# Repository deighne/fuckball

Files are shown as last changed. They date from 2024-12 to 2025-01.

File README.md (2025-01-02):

# FUCKBALL

This trackball is my update and twist on [Brickbots' aball](https://github.com/brickbots/aball) with a lot of inspiration from the [Ploopy Adept](https://github.com/ploopyco/adept-trackball). 

The biggest changes are:

- Built to use PMW3360 / PMW3389 breakout boards
- RP2040-Zero Board to keep things small and modern
- Footprint designed to sit alongside [Sofle v2](https://github.com/josefadamcik/SofleKeyboard) on either side
- A single button, as a treat

## What's the point?

I really like the simplicity of the aball design, but found its quirks kind of irritating to build. Elite-C boards aren't cheap compared to the thousands of nano boards on the market, and handwiring tiny tiny cables leaves a lot of room for error. I felt like there wasn't a great option for a buttonless trackball with a high precision sensor; the Ploopy nano is solidly entry-level, and nicer options like the Ploopy Adept are comparitively big and bulky. I think this strikes a nice balance.

## Why the breakout board and not sensor only? 

At the time of writing (December 2024), the cost difference between just a PMW3389 sensor and the sensor + breakout board with presoldered pins is just a few bucks; it's cheaper to buy the board than to get a custom PCB with assembly like the [Jfedor2 RP2040 + PMW3360 board](https://github.com/jfedor2/rp2040-pmw3360). That should make this more flexible to use other sensors in the future with the same breakout!

## License etc.

GPLv3! Do something weird with this design please.

## Fuckball?

The name wasn't already taken?

## Status

- Gerber files and Kicad are a prototype design; has not yet been printed. No guarantees! (There never are with open source any way)
- Needs BOM, guide, etc. etc. 

## Sources and Inspiration

- [Aball](https://github.com/brickbots/aball)
- [Ploopy Adept](https://github.com/ploopyco/adept-trackball))
- [Sofle](https://github.com/josefadamcik/SofleKeyboard)
- [RP2040+PMW3360](https://github.com/jfedor2/rp2040-pmw3360)

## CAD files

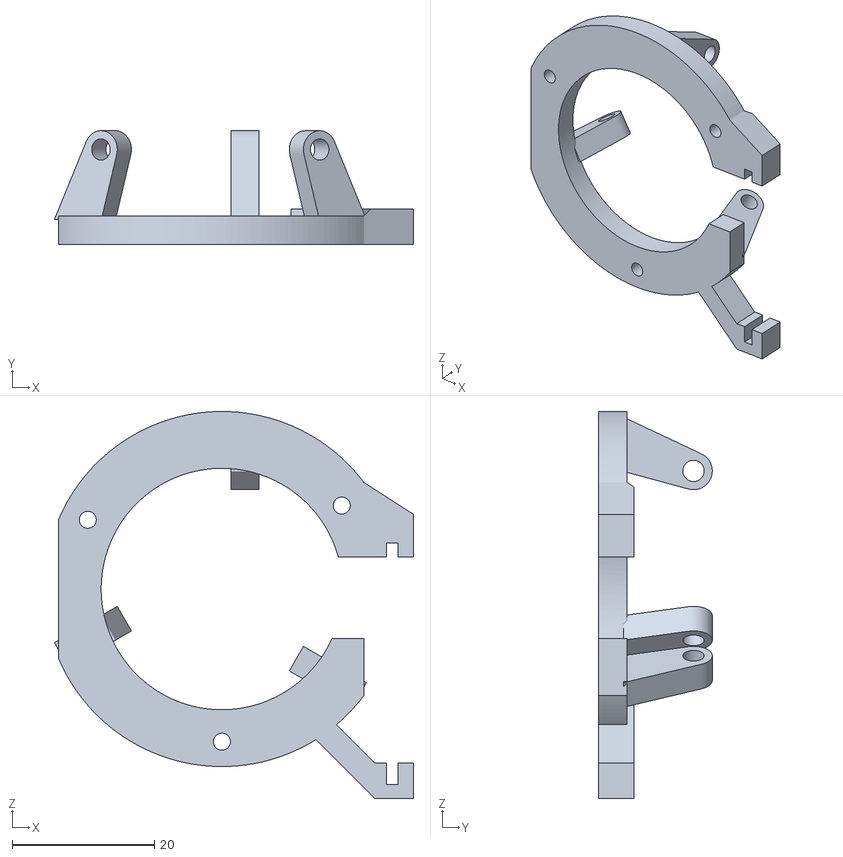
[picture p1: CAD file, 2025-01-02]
3d Printing/vertical_frame_rev4_34mm.stl
50.6 x 16.0 x 54.5

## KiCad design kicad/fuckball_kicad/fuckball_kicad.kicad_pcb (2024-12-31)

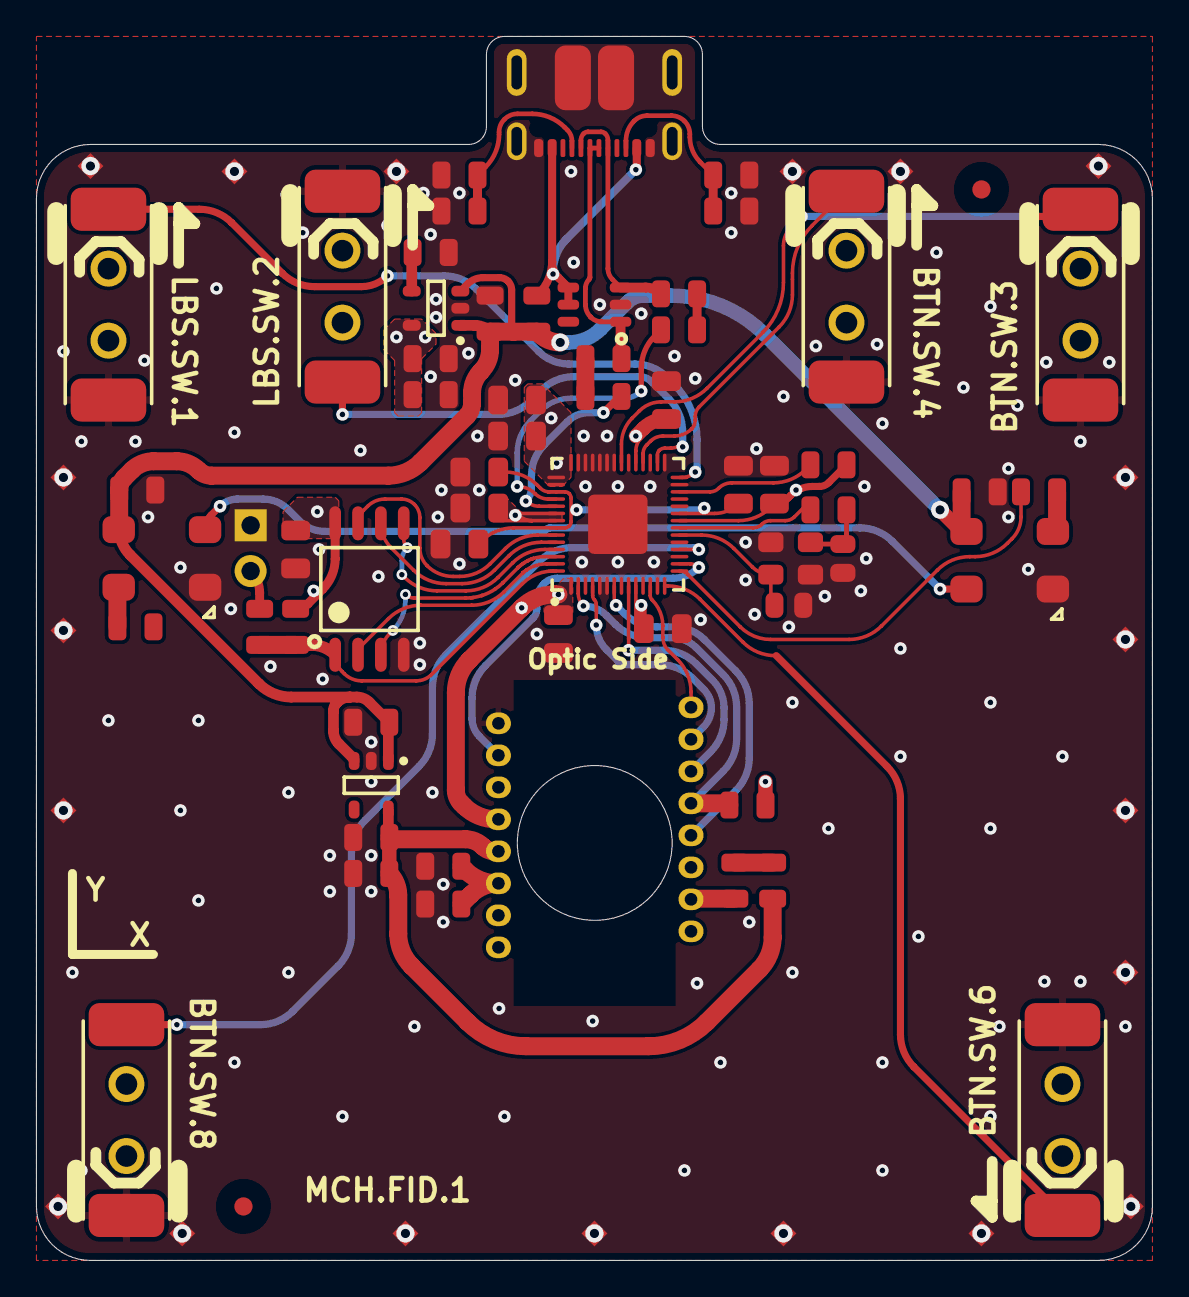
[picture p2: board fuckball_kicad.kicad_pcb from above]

Board: 4 copper layers, 62.0 x 68.0 mm, 82 parts (1 on the bottom side), 45 nets.

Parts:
BTN.SW.3, BTN.SW.4, BTN.SW.6, BTN.SW.8: D2LS-21
LBS.SW.1, LBS.SW.2: D2LS-21
LED.C.20, LED.C.23, LED.R.9, LED.R.16: 0805
LED.D.1, LED.D.3: IN-PI55TATPRPGPB
MCH.FID.1, MCH.FID.2: IPC-7351 Fiducial 1mm; FIDUCIAL_1.5
MCH.LOGO.2: Coordinate system marker for assembly; Coordinate System
MCH.SP.1, MCH.SP.2, MCH.SP.3, MCH.SP.4, MCH.SP.5, MCH.SP.6, MCH.SP.7, MCH.SP.8, MCH.SP.9, MCH.SP.10, MCH.SP.11, MCH.SP.12, MCH.SP.13, MCH.SP.14, MCH.SP.15, MCH.SP.16, MCH.SP.17, MCH.SP.18, MCH.SP.19, MCH.SP.20: Spark Gap; SparkGap
MCU.C.1, MCU.C.2, MCU.C.3, MCU.C.4, MCU.C.5, MCU.C.6, MCU.C.7, MCU.C.8, MCU.C.21, MCU.C.22, MCU.C.24: 0805 X5R; 0805 - TALL
MCU.C.9, MCU.C.19: 0603
MCU.J.1: HEADER2; 2x1
MCU.R.1, MCU.R.2, MCU.R.11, MCU.R.17: 0805
MCU.U.1: W25Q16JVSSIQ; W25Q128JVS - SOIC127P790X216-8M
MCU.U.5: RP2040; RP2040 - QFN40P700X700X90_HS-57M
MCU.Y.1: RH100-12.000-16-3030
MOS.C.10, MOS.C.11, MOS.R.3, MOS.R.4, MOS.R.5: 0805
MOS.U.2: PMW3360DM-T2QU
REG.C.12, REG.C.13, REG.C.14, REG.C.15, REG.C.16, REG.C.17, REG.C.18: 0805
REG.U.3: AP2202K-3.3; AP2202 - SOT95P270X145-5N
REG.U.4: AP2204K-1.8; AP2202 - SOT95P270X145-5N
USB.FB.1, USB.FB.2, USB.FB.3: ACML-0805-601-T; 0805
USB.J.3: DX07S016JA1R1500
USB.R.6, USB.R.7, USB.R.12, USB.R.13, USB.R.14, USB.R.15: 0805
USB.Z.1: IP4220CZ6,125; PESD3V3S4UD - SOT95P275X110-6N

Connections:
1V1: MCU.C.21.2, MCU.C.22.2, MCU.C.24.2, MCU.U.5.23, MCU.U.5.45, MCU.U.5.50
1V8: MOS.R.3.2, MOS.U.2.4, REG.C.17.2, REG.C.18.2, REG.U.4.5
3V3: MCU.C.1.2, MCU.C.2.2, MCU.C.3.2, MCU.C.4.2, MCU.C.5.2, MCU.C.6.2, MCU.C.7.2, MCU.C.8.2, MCU.R.2.1, MCU.R.17.1, MCU.U.1.8, MCU.U.5.1, MCU.U.5.10, MCU.U.5.22, MCU.U.5.33, MCU.U.5.42, MCU.U.5.43, MCU.U.5.44, MCU.U.5.48, MCU.U.5.49, MOS.R.5.2, MOS.U.2.5, REG.C.13.2, REG.C.14.2, REG.U.3.5
GND: BTN.SW.3.B, BTN.SW.4.B, BTN.SW.6.B, BTN.SW.8.A, LBS.SW.1.B, LBS.SW.2.A, LED.C.20.1, LED.C.23.1, LED.D.1.3, LED.D.3.3, MCH.SP.1.1, MCH.SP.2.1, MCH.SP.3.1, MCH.SP.4.1, MCH.SP.5.1, MCH.SP.6.1, MCH.SP.7.1, MCH.SP.8.1, MCH.SP.9.1, MCH.SP.10.1, MCH.SP.11.1, MCH.SP.12.1, MCH.SP.13.1, MCH.SP.14.1, MCH.SP.15.1, MCH.SP.16.1, MCH.SP.17.1, MCH.SP.18.1, MCH.SP.19.1, MCH.SP.20.1, MCU.C.1.1, MCU.C.2.1, MCU.C.3.1, MCU.C.4.1, MCU.C.5.1, MCU.C.6.1, MCU.C.7.1, MCU.C.8.1, MCU.C.9.2, MCU.C.19.1, MCU.C.21.1, MCU.C.22.1, MCU.C.24.1, MCU.J.1.1, MCU.U.1.4, MCU.U.5.3, MCU.U.5.5, MCU.U.5.6, MCU.U.5.8, MCU.U.5.11, MCU.U.5.13, MCU.U.5.17, MCU.U.5.19, MCU.U.5.27, MCU.U.5.29, MCU.U.5.31, MCU.U.5.34, MCU.U.5.36, MCU.U.5.37, MCU.U.5.38, MCU.U.5.39, MCU.U.5.40, MCU.U.5.41, MCU.U.5.57, MCU.Y.1.2, MCU.Y.1.4, MOS.C.10.1, MOS.C.11.1, MOS.U.2.8, REG.C.12.1, REG.C.13.1, REG.C.14.1, REG.C.15.1, REG.C.16.1, REG.C.17.1, REG.C.18.1, REG.U.3.2, REG.U.4.2, USB.J.3.1, USB.J.3.12, USB.J.3.SHELL, USB.R.12.1, USB.R.13.1, USB.R.14.1, USB.R.15.1, USB.Z.1.2
LEDData: LED.R.16.2, MCU.U.5.15
NetBTN.SW.3_A: BTN.SW.3.A, MCU.U.5.35
NetBTN.SW.4_A: BTN.SW.4.A, MCU.U.5.32
NetBTN.SW.6_A: BTN.SW.6.A, MCU.U.5.14
NetBTN.SW.8_B: BTN.SW.8.B, MCU.U.5.18
NetLBS.SW.1_A: LBS.SW.1.A, MCU.U.5.28
NetLBS.SW.2_B: LBS.SW.2.B, MCU.U.5.30
NetLED.D.1_2: LED.D.1.2, LED.D.3.4
NetLED.D.1_4: LED.D.1.4, LED.R.16.1
NetLED.D.3_2: LED.D.3.2, LED.R.9.2
NetMCU.C.9_1: MCU.C.9.1, MCU.U.5.20, MCU.Y.1.1
NetMCU.C.19_2: MCU.C.19.2, MCU.R.11.2, MCU.Y.1.3
NetMCU.J.1_2: MCU.J.1.2, MCU.R.1.1
NetMCU.R.1_2: MCU.R.1.2, MCU.R.2.2, MCU.U.1.1, MCU.U.5.56
NetMCU.R.11_1: MCU.R.11.1, MCU.U.5.21
NetMCU.R.17_2: MCU.R.17.2, MCU.U.5.26
NetMCU.U.1_2: MCU.U.1.2, MCU.U.5.55
NetMCU.U.1_3: MCU.U.1.3, MCU.U.5.54
NetMCU.U.1_5: MCU.U.1.5, MCU.U.5.53
NetMCU.U.1_6: MCU.U.1.6, MCU.U.5.52
NetMCU.U.1_7: MCU.U.1.7, MCU.U.5.51
NetMCU.U.5_2: MCU.U.5.2, MOS.R.5.1, MOS.U.2.12
NetMCU.U.5_4: MCU.U.5.4, MOS.U.2.10
NetMCU.U.5_7: MCU.U.5.7, MOS.U.2.13
NetMCU.U.5_9: MCU.U.5.9, MOS.U.2.11
NetMCU.U.5_12: MCU.U.5.12, MOS.U.2.9
NetMCU.U.5_16: MCU.U.5.16, MOS.U.2.7
NetMCU.U.5_46: MCU.U.5.46, USB.R.6.2
NetMCU.U.5_47: MCU.U.5.47, USB.R.7.2
NetMOS.C.10_2: MOS.C.10.2, MOS.C.11.2, MOS.U.2.3
NetMOS.R.3_1: MOS.R.3.1, MOS.R.4.2
NetMOS.R.4_1: MOS.R.4.1, MOS.U.2.15
NetREG.C.15_2: REG.C.15.2, REG.U.3.4
NetUSB.FB.1_1: USB.FB.1.1, USB.J.3.2, USB.J.3.11, USB.Z.1.4, USB.Z.1.5
NetUSB.FB.2_1: USB.FB.2.1, USB.J.3.5, USB.J.3.8, USB.Z.1.3
NetUSB.FB.2_2: USB.FB.2.2, USB.R.6.1
NetUSB.FB.3_1: USB.FB.3.1, USB.J.3.6, USB.J.3.7, USB.Z.1.1
NetUSB.FB.3_2: USB.FB.3.2, USB.R.7.1
NetUSB.J.3_3: USB.J.3.3, USB.R.14.2, USB.R.15.2
NetUSB.J.3_9: USB.J.3.9, USB.R.12.2, USB.R.13.2
V_USB: LED.C.20.2, LED.C.23.2, LED.D.1.1, LED.D.3.1, REG.C.12.2, REG.C.16.2, REG.U.3.1, REG.U.3.3, REG.U.4.1, REG.U.4.3, USB.FB.1.2

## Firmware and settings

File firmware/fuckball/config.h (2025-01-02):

/*
Copyright 2020 Richard Sutherland

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
You should have received a copy of the GNU General Public License
along with this program.  If not, see <http://www.gnu.org/licenses/>.
*/

#pragma once

// #define SPI_DRIVER SPID0
#define PMW33XX_LIFTOFF_DISTANCE 0x00
#define PMW33XX_CS_PIN GP13
#define SPI_SCK_PIN GP10
#define SPI_MISO_PIN GP4
#define SPI_MOSI_PIN GP7
// #define ROTATIONAL_TRANSFORM_ANGLE -180 // Optional: Rotates the trackball
#define POINTING_DEVICE_INVERT_Y // Optional: Inverts trackball X
#define RP2040_BOOTLOADER_DOUBLE_TAP_RESET

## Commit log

2024-12-31 v. 0.001 - just cleaning up the rep
    [D2LS_21.step, K3D-DX07S016JA1-V1_JAE_Proprietary.STEP, PMW3360-LM19-LSI-Assembly.stp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]
2025-01-02 v. 0.002
    [Adept-Rev3.3mf, Adept-Rev3.STEP, Buttons.SchDoc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]
2025-01-02 v. 0.01
    [fuckball-bottom-B_Cu.gbr, fuckball-bottom-B_Mask.gbr, fuckball-bottom-B_Paste.gbr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]

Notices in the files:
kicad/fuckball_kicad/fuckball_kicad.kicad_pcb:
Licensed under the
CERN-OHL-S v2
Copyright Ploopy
